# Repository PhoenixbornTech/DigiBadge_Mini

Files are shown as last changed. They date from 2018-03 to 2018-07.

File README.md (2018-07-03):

# DigiBadge_Mini
Upgraded and updated version of the [V2 DigiBadge](https://github.com/PhoenixbornTech/DigiBadgeV2). While keeping the same size profile, a few updates and changes have been made to the board and its software. But of course, you're wondering: What are the changes?

 - Added a small flash memory chip
 - Replaced the control "stick" with a set of three buttons
 - Broke out many pins: Analog 0-7 and Digital 2, 3, 4, 11, 12, and 13, along with VCC and GND. Buttons 0, 1, and 2 are assigned to D2, D3, and D4 respectively. I2C is available via A4 and A5, and SPI is available on D11, D12, and D13.
 - The FTDI connector is also broken out. If the FTDI chip isn't present, GND, VCC, RST, D0, and D1 can be accessed. 
 - No power switch! Instead, the device can be put into a super low power mode that effectively doesn't use any power, just like a TV remote.
 - The board has been redesigned so that these can be ordered and manufactured, instead of being entirely hand-assembled.
 - Other minor board tweaks have been made, including making the entire device not hard reset when an SD card is inserted.
 
## Plans for the FUTURE!
After selling these at BABSCon and getting some real-world usage out of them, there are a few things that need to be addressed, largely in the hardware. These fall under the category of [**Revision 2**](https://github.com/PhoenixbornTech/DigiBadge_Mini/milestone/3). Currently, those goals are:

 - Improving the buttons. The current ones are inexpensive, but not the easiest or most intuitive to use.
 - Labeling the FTDI orientation. The R1 board has no indication of pin direction, which can be annoying.
 - Add reverse voltage protection, to ensure nobody fries their board by accidentally putting the batteries in backwards.
 - Adding a voltage regulator. This will allow for consistent backlight brightness and utilizing more of the battery for a longer battery life. This will also allow for LiPo batteries to be used as well.
 
## How it works

With the latest releases, the DigiBadge operates using a Menu system that should be fairly straightforward.

From within a mode, pressing the left or right buttons will change which badge/flag/image is displayed, while pressing the center button will access the menu.

While in the Menu, pressing the left button (When looking at the screen) moves the cursor up, pressing the right button moves the cursor down, and the center button accesses the current selection. If the selection is a mode, the badge goes to that mode. If it is another menu, such as brightness, it goes into that menu.

Bear in mind that while the Slideshow Time menu will automatically return to the main menu on making a selection, **Brightness will not**. This is so you can select a brightness and see the difference. Exiting the menu locks the selection in.
 
The DigiBadge has four modes, in the order that they cycle through: **Color Communication Badge**, **Image Slideshow**, **Static Image**, and **Pride Flags**. Image Slideshow and Static Images are inaccessible (And greyed out) when there is no SD card detected.

The DigiBadge will *automatically* load the SD card when it is inserted. Thanks to moderately recent updates to the default Arduino library, this no longer requires edits to the SD library.
 
## Color Communication Badges
 
Color Communication Badges were *inspired* by BronyCon's use of them, but they were *originated* by the Autism Self-Advocacy Network. You can read what ASAN has to say on the Color Communication Badges on [their website](http://autisticadvocacy.org/2014/02/color-communication-badges/).
 
The badges on the DigiBadge are not identical to ASAN or BronyCon versions, as they have been adapted for viewing on a small screen. In the future, it would be great to allow for users to select a preference for style of these badges, but at the moment it is uncertain if that can be fit onto a device with the limited memory of an ATMega328p.

What you see on the DigiBadge is not an image file - It's programatically created each time it is displayed.
 
## Pride Flags
 
The DigiBadge also includes a variety of Pride Flags for users to display. Only a few flags were omitted, and those were ones that would be difficult to display programatically. As with the Color Communication Badges, these are created each time they are displayed.

There are currently *seven* Pride Flags built in to the DigiBadge Mini, in the order they appear: The **LGBT+ Flag**, the **Bisexual Flag**, the **Transexual Flag**, the **Pansexual Flag**, the **Asexual Flag**, the **Nonbinary Flag** and the **Agender Flag**.

## Image and Slideshow Modes

The Image and Slideshow modes are closely related. Both of them display 24-bit BMP images loaded from the SD card. Both of them will be skipped if no SD card is present. The difference is that the **Static Image** mode will display the image until told to change. The **Slideshow** mode will display a new semi-random image (It won't pick the current or previous image) every few seconds, and will display a "Play" icon in the corner.

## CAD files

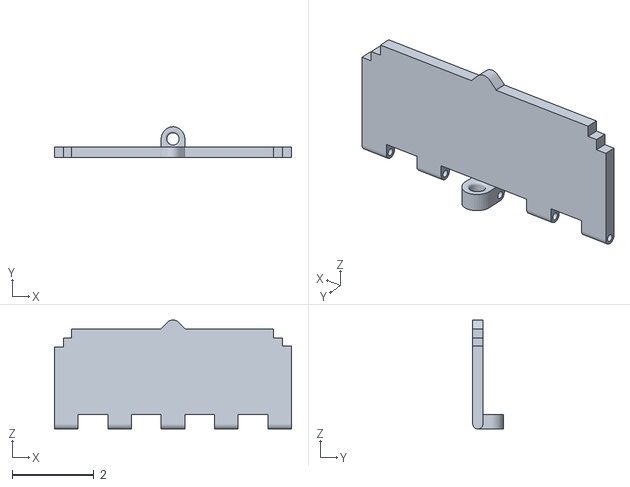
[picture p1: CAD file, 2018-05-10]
Case/DigiBadge V2 & Mini Lid.stl
5.80 x 0.75 x 2.67

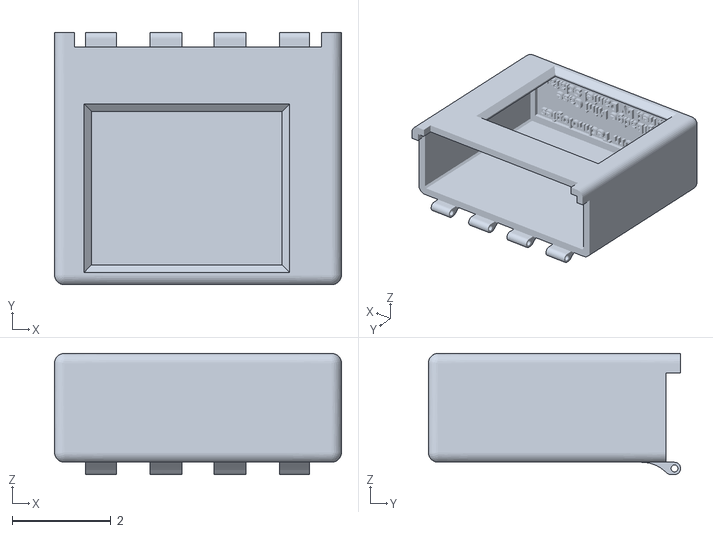
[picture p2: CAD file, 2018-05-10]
Case/DigiBadge Mini Case.stl
5.80 x 5.10 x 2.45

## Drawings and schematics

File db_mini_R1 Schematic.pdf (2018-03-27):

2 R1
10kΩ

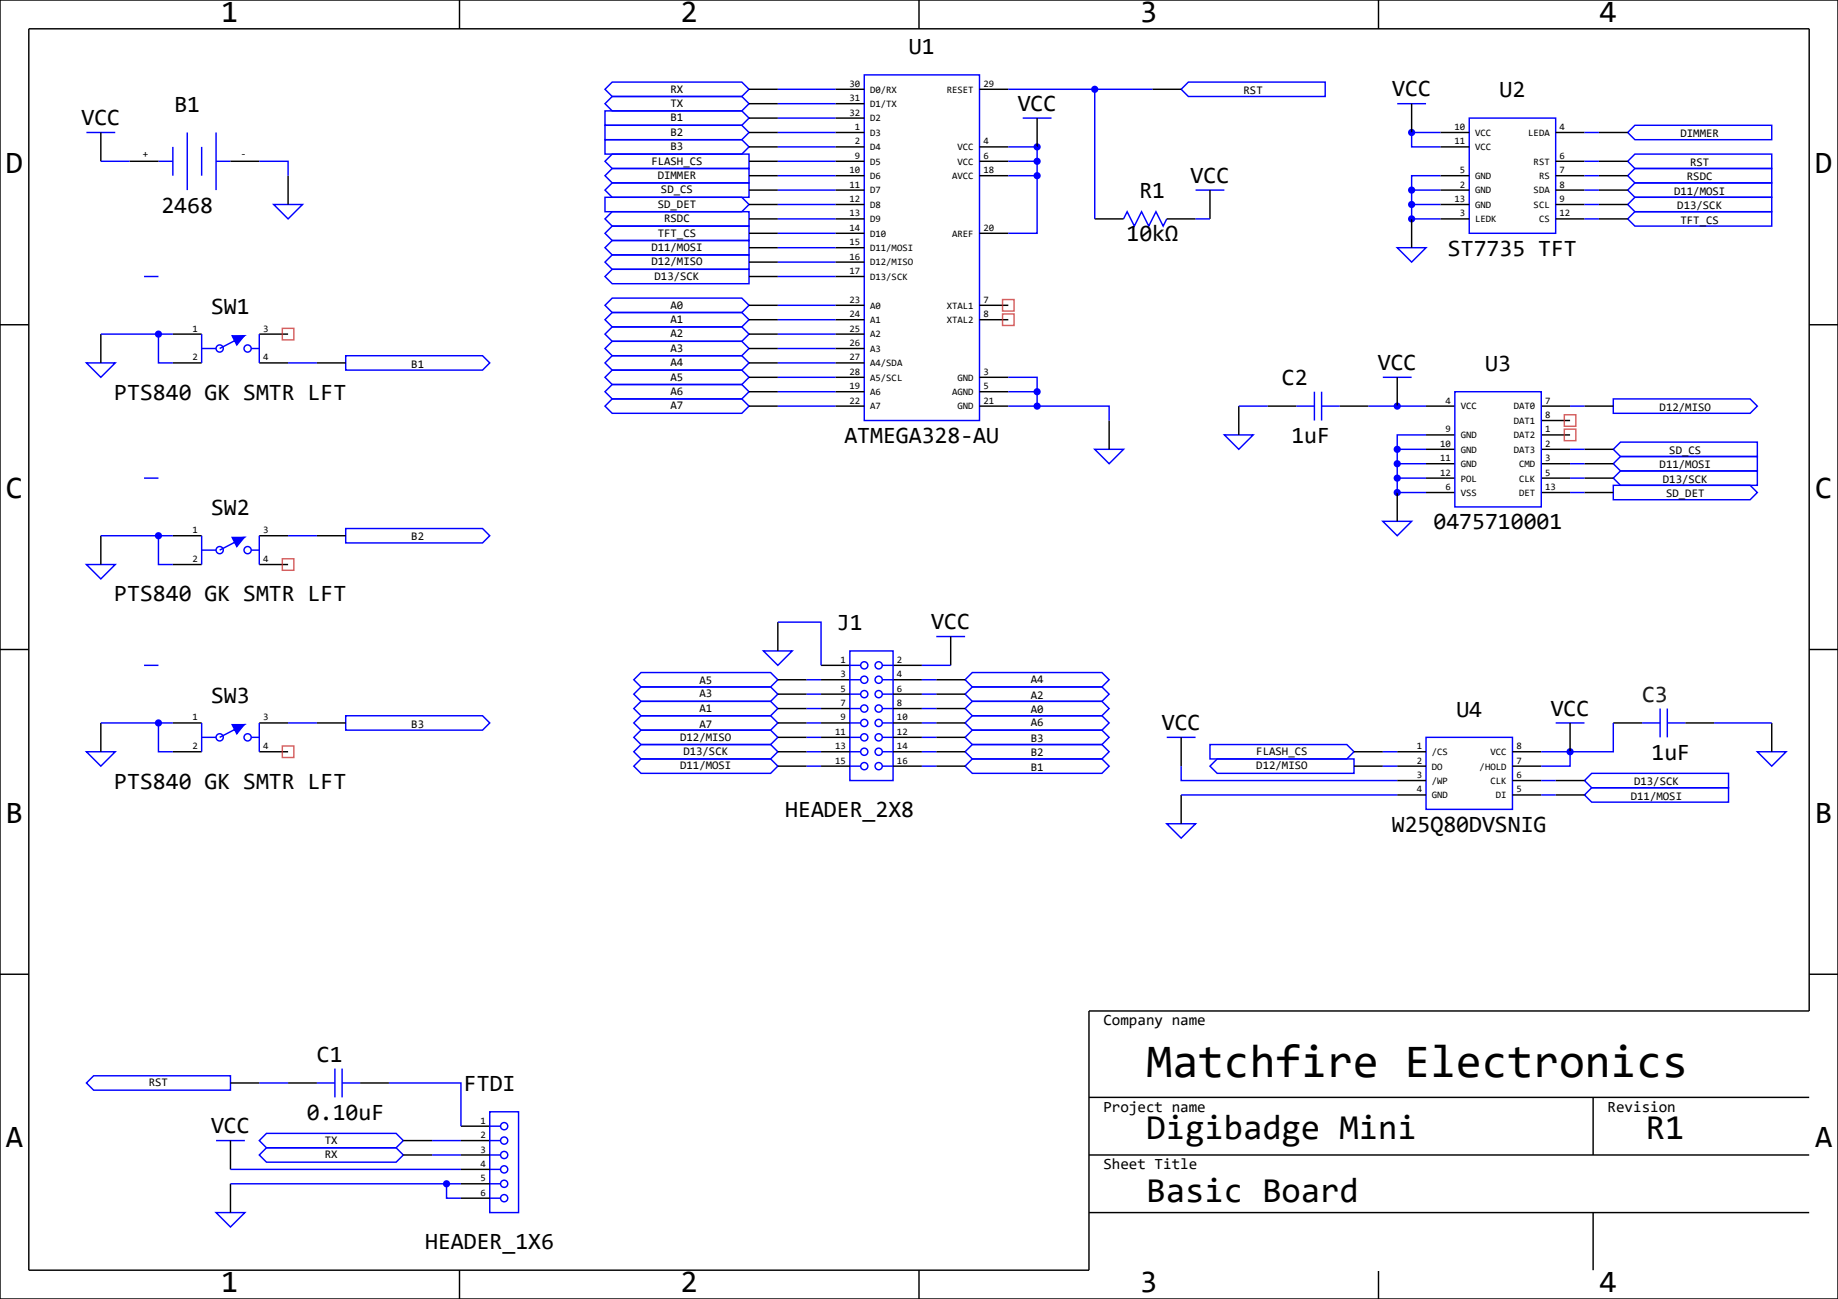
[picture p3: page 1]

Company name
Matchfire Electronics
Project name Digibadge Mini
Basic Board

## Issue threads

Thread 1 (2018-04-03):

Allow SD card to be loaded/re-loaded after startup

Andon-A, 2018-04-03:
Current implementation of the code does not allow for insertion of SD cards while the badge is running. The device needs to be manual hard reset.

Goals of this issue:

1. Enable the SD Card detection pin.
2. If a badge is running without a SD card and one is inserted, load it.
3. If a badge is running with an SD card and it is removed and re-inserted, reset the device. Without hacking the standard Arduino SD library, SD cards can't be reloaded.

Andon-A, 2018-05-06:
Commit [34ad042](https://github.com/PhoenixbornTech/DigiBadge_Mini/commit/121404a65850b7c9b673193664cdcd8491277d15) addresses this issue.

It functions *slightly* different than initial goals:

1. SD Card Detection is functioning, to enable the following:
2. If there is no SD card and one is inserted, the device will reset to load them (As the standard Arduino SD library doesn't allow reloading SD cards)
3. If there is an SD card and it is removed, the device adjusts the image count appropriately, and will then skip the image modes.

Closed 2018-05-06.

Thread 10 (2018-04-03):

Label FTDI Orientation

Andon-A, 2018-04-03:
Current FTDI orientation is unclear just by looking at the device. Improving the silkscreen to clearly mark the orientation would help immensely.

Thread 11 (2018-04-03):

Add Flash chip support

Andon-A, 2018-04-03:
Currently, the flash chip exists, but isn't used. That should be fixed.

Andon-A, 2018-05-07:
Commit [6288e9b](https://github.com/PhoenixbornTech/DigiBadge_Mini/commit/4f85b5977f58126d404e0ca74ab1a4cb20c3d47c) adds the SPIFlash library and utilizes it.

Closed 2018-05-07.

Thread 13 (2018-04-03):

Add .STL files for 3D Printed Case

Andon-A, 2018-04-03:
The goal is to have everything 100% open source, including the case files.

Andon-A, 2018-05-12:
These have been uploaded under the "Cases" folder.

Closed 2018-05-12.

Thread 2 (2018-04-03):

Software Reset

Andon-A, 2018-04-03:
A handful of things are easier if software reset is enabled. There are methodologies for an Arduino device to reset itself. One should be implemented.

Andon-A, 2018-04-03:
Code for the software reset will be used by #1 but allowing willing access/deliberate resets are further in the future.

Andon-A, 2018-05-12:
Not needed, and with the Menu System code taking up every last byte, it won't be implemented.

Closed 2018-05-12.

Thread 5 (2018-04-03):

Menu System

Andon-A, 2018-04-03:
Adding a menu system will allow more options, such as selecting modes without flipping through all of them, manually resetting the device, and the like. It will also allow the user to change options such as length between images in slideshow mode, or if the play button is shown in slideshow mode, or backlight brightness, and the like.

Andon-A, 2018-05-12:
Menu System has been completed and uploaded, with the pull request on my other monitor.

Closed 2018-05-12.

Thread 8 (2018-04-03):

Add Voltage Regulator

Andon-A, 2018-04-03:
A voltage regulator would allow for a significant increase in the utility of the device.

Things to keep in mind:

1. Boost regulating would allow for significant extension of battery life.
2. Adding a high/low regulator would allow for LiPo battery connection. If the appropriate regulator is selected, this could even apply to two LiPo AAA-sized cells.
3. Any regulator increases cost.
4. Physical space on the device is at a premium.

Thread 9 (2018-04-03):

Add Reverse Voltage Protection

Andon-A, 2018-04-03:
Ensuring that backwards batteries don't cause issues is always a good thing. It shouldn't be difficult to include the FTDI connector in the protection as well.

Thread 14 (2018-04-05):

Improve Buttons

Andon-A, 2018-04-05:
With the current button designs, people have a tendency to press perpendicular to the circuit board, instead of parallel from the top of the screen.

Sourcing buttons that are more visible and clearer as to their function would alleviate this issue.

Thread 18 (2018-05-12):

Update SD to use "SD Reset"

Andon-A, 2018-05-12:
Version 1.2.0 of the official Arduino SD library included [this fix](https://github.com/arduino-libraries/SD/pull/38), which allows for re-initialization of SD cards.

Rather than force-resetting the whole device, the SD card should be re-loaded when re-inserted.

This may make a software hard reset impossible, but it might not. Depends on how much space it needs. It may free up space.

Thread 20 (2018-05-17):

SPIMemory eats program space.

Andon-A, 2018-05-17:
SPIMemory (Formerly SPIFlash) eats twice as much program memory as the earlier version.

Something needs to be solved.

Current workaround: Use Verison 3.1.0 found [here](https://github.com/Marzogh/SPIMemory/releases/tag/v3.1.0)

Andon-A, 2018-05-17:
Additionally, SPIFlash.h, line 36 and line 64 need to be commented out on Version 3.1.0 - RUNDIAGNOSTIC and PRINTNAMECHANGEALERT, respectively.

Andon-A, 2018-05-22:
Looks like this should be addressed now: https://github.com/Marzogh/SPIMemory/issues/135

Marzogh reports that between fixes and a new memory-saving option, an additional 394 bytes are saved! That gives a lot of wiggle room for other things.

Andon-A, 2018-05-24:
Closing, as [This Commit](https://github.com/PhoenixbornTech/DigiBadge_Mini/commit/f57dc92b90c6c85ee3cc7d2d009534e7bb0dc764) fully integrates SPIMemory.

SPIMemory defaults to commenting out  `#define RUNDIAGNOSTIC` and `#define USES_SFDP`, so no modifications are needed to save space. Just install and go!

Closed 2018-05-24.

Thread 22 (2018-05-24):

Add Power LED

Andon-A, 2018-05-24:
Add an LED (Preferably to the front) that turns on when powered.

Potential issue: Having it on only when the device is on and not in sleep. Need to look into that.

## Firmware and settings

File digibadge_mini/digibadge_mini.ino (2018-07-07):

//DigiBadge Mini
//TODO list:
//-Backlight Control
//-TFT controls
//-Flash startup

//Libraries for TFT, SPI, SD, and flash.
#include <Adafruit_GFX.h>     // https://github.com/adafruit/Adafruit-GFX-Library
#include <Adafruit_ST7735.h>  // https://github.com/adafruit/Adafruit-ST7735-Library
#include <LowPower.h>         // https://github.com/rocketscream/Low-Power
#include <SPIMemory.h>         // https://github.com/Marzogh/SPIMemory
#include <SPI.h>
#include <SD.h>

//Defines.
//TFT CS is 10, DC is 9. TFT reset is tied to board reset.
#define BKLT 6 //Display backlight pin.
#define SDCS 7 //Chip Select for SD card
#define SDCD 8 //Card Detect line for SD card
#define FLCS 5 //Chip Select for Flash memory.
#define B0 2 //Button 0, or far left when viewing screen
#define B1 3 //Button 1, or center button
#define B2 4 //Button 2, or far right/next to SD card
#define BWK 0 //Wake on Interrupt 0/Button 0 press. Button 1 is also an option.
#define LowV 2800 //Low Voltage warning, in millivolts
#define CritV 2700 //Critical Voltage. Shut down below this.
#define LLEN 125 //Milliseconds the loop waits for.
#define VLEN 16 //Number of cycles before checking battery. 16 cycles at 125ms is about once every two seconds..

//Set up TFT and Flash
Adafruit_ST7735 tft = Adafruit_ST7735(10, 9, -1);
SPIFlash flash(FLCS);

//Code version.
//The byte or two extra in the code is used to allow slight variations in string size.
#define cver F("v1.2c")

//Variables.
byte x = 0;
byte scycles = 40; //Number of cycles it waits for slideshow.
byte bright = 10; //Brightness amount, in percent
byte md = 0; //Mode: 0 = Badge, 1 = Slideshow, 2 = Static Image, 3 = Flags
byte oldmd = 0; //Old mode. For when you enter the menu and just want to exit it.
byte badge = 0; //Current badge. 0 = Yellow, 1 = Red, 2 = Green
byte flag = 0; //Current flag. 0 = LGBT, 1 = Bi, 2 = Trans, 3 = Pan, 4 = Ace
byte menu = 0; //Current menu. 0 = main, 1 = slide speed, 2 = brightness, 3 = device info
byte select = 0; //Current menu selection. Line number. 0 = off.
byte oldselect = 0; //Old selection. For quickly re-displaying cursor.
byte bobs = 0; //Byte that stores bools as bits.
                //Bits 0, 1, and 2 are the respective Buttons.
                //Bit 3 is "SD Present" - For returning the status of the SD card detector.
                //Bit 4 is "Reset Timer" - Generally, when we manually change the image in a slideshow.
                //Bit 5 is "New Display" - Changing badge, changing image, etc
                //Bit 6 is "Low Battery"
                //Bit 7 is "Just Woke"
byte oldbobs = 0; //Storing previous buttons, to check against.
uint16_t imgnum = 0; //How many images we have.
uint16_t imgcur = 0; //Current image we are displaying.

void setup() {
  pinMode(B0, INPUT_PULLUP);
  pinMode(B1, INPUT_PULLUP);
  pinMode(B2, INPUT_PULLUP);
  pinMode(SDCD, INPUT_PULLUP);
  startSD();
  startFlash();
  startTFT();
  delay(2500); //Pause so we can actually SEE the screen.
  updateScreen();
}

void loop() {
  // put your main code here, to run repeatedly:
  x += 1;
  if (bitRead(bobs, 7)) {
    //We just woke up, so remove the interrupt and turn the screen back on.
    detachInterrupt(BWK); //Remove the interrupt.
    digitalWrite(6, HIGH);
    bitClear(bobs,7);
    x = 0; //Reset our counter.
    //GetBattery is deliberately placed after we turn back on.
    //This allows for the device to show something, although briefly.
    getBattery();
    delay(250); //Give us time to let go of buttons.
  }
  //Get our buttons. changed.
  getButtons();
  runButtons();
  //Next image in slideshow.
  if ((x % VLEN) == 0){
    //Check voltage.
    getBattery();
  }
  if (x > scycles){
    if (md == 1){
      //Change image if we're in slideshow mode.
      imgcur = randBMP();
      bitSet(bobs,5);
    }
    getBattery();
    x = 0;
  }
  //Update our screen if we have to.
  if (bitRead(bobs,5)){
    updateScreen();
    //Now that we've updated it, reset it.
    bitClear(bobs, 5);
  }
  if (bitRead(bobs, 4)){
    //We're resetting our timer.
    x = 0;
    bitClear(bobs, 4);
  }
  delay(LLEN);
}

void updateScreen(){
  if (md > 4){
    md = 0; //Just to be sure.
  }
  if (md == 0){
    //Badge Mode.
    drawBadge(badge);
  }
  else if ((md == 1) or (md == 2)){
    bmpDraw(grabBMP(imgcur),0,0);
  }
  else if (md == 3){
    drawFlag(flag);
  }
  else if (md == 4){
    drawMenu(menu, select);
  }
  if (md == 1){
    drawPlayIcon(146,2);
  }
}

void getButtons() {
  //Uses the first three bits of byte "bobs" as bools for buttons.
  oldbobs = bobs; //Store the previous iterations.  
  //Button 0. Left side facing screen.
  if (digitalRead(B0)){
    bitSet(bobs, 0);
  }
  else {
    bitClear(bobs, 0);
  }
  //Button 1. Center.
  if (digitalRead(B1)){
    bitSet(bobs, 1);
  }
  else {
    bitClear(bobs, 1);
  }
  //Button 2. Next to SD card.
  if (digitalRead(B2)){
    bitSet(bobs, 2);
  }
  else {
    bitClear(bobs, 2);
  }
  //SD Card Detect
  if (!digitalRead(SDCD)){
    //We have an SD card.
    bitSet(bobs, 3);
    if (bitRead(bobs, 3) and (!bitRead(oldbobs, 3))){
      //We now have an SD card, when we didn't before.
      //Attempt to re-start the SD card.
      startSD();
      bitSet(bobs, 5); //This makes it easy to notice things have loaded. Especially in a menu.
    }
  }
  else {
    bitClear(bobs, 3);
    if bitRead(oldbobs, 3) {
      //SD card removed while running.
      //We can't use images now.
      imgnum = 0;
      imgcur = 0;
      bitSet(bobs, 5); //As with above, makes it more noticeable that things have changed.
    }
  }
}

long getBattery(){
  //Retrieves the voltage of the batteries.
  //Using method prodivded at http://provideyourown.com/2012/secret-arduino-voltmeter-measure-battery-voltage/
  //Read the 1.1V internal reference against AVcc
  // Set the reference to VCC and measure the difference between the 1.1v and reference.
  ADMUX = _BV(REFS0) | _BV(MUX3) | _BV(MUX2) | _BV(MUX1);
  delay(2); //Allow Vref to settle.
  ADCSRA |= _BV(ADSC); // Start conversion
  while (bit_is_set(ADCSRA, ADSC)); // measuring
  uint8_t low  = ADCL; // must read ADCL first - it then locks ADCH
  uint8_t high = ADCH; // unlocks both
  long mV = (high << 8) | low;
  mV = 1125300L / mV; // Calculate Vcc (in mV); 1125300 = 1.1*1023*1000
  if (mV <= LowV){
    //We have low voltage.
    //Batteries are still fairly good, but backlight power starts waning quite fast.
    bitSet(bobs, 6);
  }
  else if ((mV > (LowV + 250)) and bitRead(bobs, 6)){
    //If "Low Battery" bit is set, and we are now higher than the Low Voltage, clear the low battery alert.
    //A small cushion is added to ensure we don't get a set/unset with voltage fluctuations.
    //Realistically speaking, we won't need this, but there's a chance we'll go to, say, external power.
    bitClear(bobs, 6);
  }
  if (mV <= CritV){
    //We turn off at this point.
    //As we check the battery voltage fairly often, we can just shut off.
    digitalWrite(6, LOW);
    attachInterrupt(BWK, wakeUp, LOW);
    delay(300);
    LowPower.powerDown(SLEEP_FOREVER, ADC_OFF, BOD_OFF); 
  }
  return mV;
}

void runButtons(){
  //New, for Menus!
  //Improvements: "else if" instead of "if"
  //Ensures proper button priority.
  //bitSet(bobs, 5); //Menus won't require full screen reset.
  if (!bitRead(bobs, 1)){
    //Button 1 (Center)
    //Most important button!
    bitSet(bobs, 5); //We're changing menus, or modes.
    //If we're in a non-Menu mode, bring us to Menu mode.
    if(md != 4){
      oldmd = md;
      md = 4;
      menu = 0;
      select = 1;
    }
    else if(md == 4){
      //Do the thing. For the menu.
      if (menu == 0){
        if(select == 1){
          md = 0; //Enter Badge Mode.
        }
        else if (select == 2){
          md = 3; //Enter Flag Mode.
        }
        else if ((select == 3) and (imgnum > 0)){
          md = 2; //Enter Image mode, but only if we have images.
        }
        else if ((select == 4) and (imgnum > 1)){
          md = 1; //Enter Slideshow mode, but only if we have images.
          x = 0; //Reset our timer, just in case.
        }
        else if ((select == 4) and (imgnum == 1)){
          md = 2; //Enter image mode for one image.
        }
        else if (select == 5){
          menu = 3; //Device Info
          select = 0;
        }
        else if (select == 6){
          menu = 1; //Slideshow speed
          select = 1;
        }
        else if (select == 7){
          menu = 2; //Brightness.
          select = 1;
        }
        else if (select == 8){
          md = oldmd; //Make sure we wake up in our old mode.
          //saveSettings(); //Save settings. Shouldn't be needed, but we ARE turning off, so...
          napTime();
        }
        if(((select >=1) and (select <= 4)) or (select == 8)){
          //We're selecting a mode, OR shutting down.
          saveSettings();
        }
      }
      else if (menu == 1){
        //Slideshow speed!
        if((select > 0) and (select < 13)){
          //We're selecting a delay.
          scycles = 8 * select; //Yay simple!
          x = 0; //Reset to 0 for slideshow shenanigans.
          select = 1;
          menu = 0;
        }
        else {
          //Exiting this menu.
          select = 1;
          menu = 0;
        }
      }
      else if (menu == 2){
        //Brightness
        if((select > 0) and (select < 11)){
          //We're selecting a brightness.
          bright = 10 * select;
          setLight(bright);
          //So, to easily see results and change them
          //DON'T exit tue current menu.
          //Also don't redraw it.
          bitClear(bobs, 5);
        }
        else {
          //Exit this menu. Save settings.
          select = 1;
          menu = 0;
        }
      }
      else if (menu == 3){
        //Device Info!
        //Simply return to main menu.
        select = 1;
        menu = 0;
      }
    }
  }
  else if (!bitRead(bobs, 0)){
    //Button 0 (Far left when looking at screen)
    if (md == 0){
      //Badge mode. Decrese badge by one.
      badge -= 1;
      if (badge > 2){
        //Only three badges.
        badge = 2; //We're decreasing, so go to the highest.
      }
    }
    else if (md == 1){
      //Slideshow!
      //New random image.
      imgcur = randBMP();
    }
    else if (md == 2){
      //Still image.
      imgcur -= 1; //Reduce by one!
      if (imgcur > imgnum){
        //We've wrapped around.
        imgcur = imgnum;
      }
    }
    else if (md == 3){
      //Flags!
      flag -= 1;
      if (flag > 6){
        //Wrap around
        flag = 6;
      }
    }
    else if (md == 4){
      //Go "Down" in the menu selection.
      oldselect = select;
      if (menu == 0){
        //Main menu. 8 max.
        select -= 1;
        if (select == 0){
          select = 8;
        }
      }
      else if (menu == 1){
        //Slideshow Time Menu. 13 max.
        select -= 1;
        if (select == 0){
          select = 13;
        }
      }
      else if (menu == 2){
        //Brightness. 11 Max.
        select -= 1;
        if (select == 0){
          select = 11;
        }
      }
      drawCursor(select, oldselect);
    }
  }
  else if (!bitRead(bobs, 2)){
    //Button 2 (Far right, next to SD card)
    if (md == 0){
      //Badge mode. Increase badge by one.
      badge += 1;
      if (badge > 2){
        //Only three badges.
        badge = 0; //Increasing, so wrap around.
      }
    }
    else if (md == 1){
      //Slideshow!
      //New random image.
      imgcur = randBMP();
    }
    else if (md == 2){
      //Still image.
      imgcur += 1; //Increase by one!
      if (imgcur > imgnum){
        //We've wrapped around.
        imgcur = 1;
      }
    }
    else if (md == 3){
      //Flags!
      flag += 1;
      if (flag > 6){
        //Wrap around
        flag = 0;
      }
    }
    else if (md == 4){
      //Go "Up" in the menu selection.
      oldselect = select;
      if (menu == 0){
        //Main menu. 8 max.
        select += 1;
        if (select > 8){
          select = 1;
        }
      }
      else if (menu == 1){
        //Slideshow menu. 13 max.
        select += 1;
        if (select > 13){
          select = 1;
        }
      }
      else if (menu == 2){
        //Brightness menu. 11 max.
        select += 1;
        if (select > 11){
          select = 1;
        }
      }
      drawCursor(select, oldselect);
    }
  }
  if ((!bitRead(bobs, 0) or !bitRead(bobs,2)) and (md != 4)){
    //All non-Menu changes require screen update and settings save.
    bitSet(bobs, 5);
    saveSettings();
  }
}

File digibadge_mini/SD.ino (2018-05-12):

void startSD(){
  //We haven't checked any buttons yet, so do it manually.
  if (!digitalRead(SDCD)) {
    //We have an SD card physically present. Attempt to start it.
    bitSet(bobs, 3); //To prevent from immediately resetting.
    if (SD.begin(SDCS)) {
      imgnum = countBMP();
      if (imgnum > 0) {
        //"Current Image" starts at 1. Adjust accordingly.
        imgcur = 1;
      }
    }
  }
}

uint16_t countBMP(){
  uint16_t bmpcount = 0;
  //Open directory, then rewind it. Just in case someone hasn't been kind.
  File dir = SD.open("/");
  dir.rewindDirectory();
  //Start checking files.
  File fi = dir.openNextFile();
  while (fi) {
    //Check it.
    if (bmpCheck(fi)){
      //We have a valid, 24-bit BMP file.
      bmpcount += 1;
    }
    //We're done here.
    fi.close();
    delay(5); //Don't go too fast.
    fi = dir.openNextFile();
  }
  dir.rewindDirectory();
  dir.close();
  return bmpcount;
}


bool bmpCheck(File bmpFile) {
   //Check a File to see if it's an appropriate BMP file.
   //Silently fail directories.
   //if (bmpFile.isDirectory()){
   // return false; 
   //}
   if (read16(bmpFile) == 0x4D42) { // BMP signature
    (void)read32(bmpFile); //Read, but ignore, file size.
    (void)read32(bmpFile); //Same with creator bytes
    (void)read32(bmpFile); //Same with start of image data.
    (void)read32(bmpFile); //Header size.
    (void)read32(bmpFile); //Width.
    (void)read32(bmpFile); //Height.
    (void)read16(bmpFile); //Planes.
    //Now the important stuff!
    //First is Bit Depth and second is Compression.
    if((read16(bmpFile) == 24) && (read32(bmpFile) == 0)){
      return true;
    }
    //else {
      //Not a 24-bit BMP file.
    //  return false;
    //}
  }
  else {
    //File is not a BMP
    return false;
  }
}

uint16_t randBMP(){
  //Returns a random image number.
  //Makes sure we don't pull the current or previous image, unless there are only two images.
  if (imgnum == 1){
    //Only one image.
    return 1;
  }
  else if (imgnum == 2){
    //Two images. Return the previous image.
    if (imgcur == 1){
      return 2;
    }
    else {
      return 1;
    }
  }
  else {
    uint16_t res = random(1,imgnum+1);
    while (res == imgcur){
      res = random(1,imgnum+1);
    }
    return res;
  }
}

uint16_t numBMP(char* filename){
  uint16_t count = 0;
  File dir = SD.open("/");
  dir.rewindDirectory();
  File fi = dir.openNextFile();
  while(fi){
    if (bmpCheck(fi)){
      //A valid BMP.
      count += 1; 
    }
    if (fi.name() == filename){
      fi.close();
      dir.rewindDirectory();
      dir.close();
      return count;
    }
    fi.close();
    delay(5);
    fi = dir.openNextFile();
  }
  dir.rewindDirectory();
  dir.close();
  return 0;
}

char* grabBMP(uint16_t bmpnum){
  if (bmpnum > imgnum) {
    //We don't have that many images.
    //Retrieve the last one.
    bmpnum = imgnum;
  }
  uint16_t count = 0;
  File dir = SD.open("/");
  dir.rewindDirectory();
  char* bmpName;
  File fi = dir.openNextFile();
  while(fi) {
    if (bmpCheck(fi)){
      //A valid file.
      count += 1; //Increment the count.
      if (count == bmpnum){
        //The file we want
        bmpName = fi.name();
        fi.close();
        dir.rewindDirectory();
        dir.close();
        return bmpName;
      }
    }
    //Close the file, move to next one.
    fi.close();
    delay(5);
    fi = dir.openNextFile();
  }
  //Give us the name.
  dir.rewindDirectory();
  dir.close();
  return bmpName;
}

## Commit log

2018-05-06 Fixes border issues on LGBT Flag
    Fixes border issues on LGBT flag.
    [flags.ino]
2018-05-06 Allow hot-swapping of SD cards
    Addresses issue #1 Utilizes a device reset when a card is inserted.
    Updates images when card is removed.
    [SD.ino, sleeproutines.ino]
2018-05-06 Updated README
    Added descriptions of what everything does, and what buttons do what,
    etc.
2018-05-10 Added case .STL files
    Uploaded the STL files for the DigiBadge Mini case.
    [DigiBadge Mini Case.stl, DigiBadge V2 & Mini Lid.stl]
2018-05-10 Organization
    Moved case files to their own folder. Should have done that to begin
    with.
    [DigiBadge Mini Case.stl, DigiBadge V2 & Mini Lid.stl]
2018-05-11 Remove "proto" from code name
    Not a prototype anymore.
2018-05-12 Updates with links to libraries
    Updates digibadge_mini.ino with links to the Arduino libraries used.
    Also worth noting that after I updated my versions of these libraries,
    there are now 34 bytes available.
2018-05-12 SD Reloading
    Addresses #18 to allow a smoother loading of SD card.
    Also addresses minor bug with Flags - If the number was out of range,
    they'd fail to load entirely.
    More code cleanup is included as well.
    [SD.ino, TFT.ino, digibadge_mini.ino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]
2018-05-15 Fixes defaulting to badge mode bug
    Fix for #19 and clarification of code version comment.
    [digibadge_mini.ino]
2018-05-24 SPIMemory, Bugfixes, and Flash Error Checking
    Updates to SPIMemory flash library, which saves some space.
    Fixes the badge not remembering Slideshow/Still Image mode on full
    reboot
    Adds error checking to ALL settings when loading from flash memory, and
    updates a few other checks to be more thorough.
    [badges.ino, digibadge_mini.ino, flags.ino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]
2018-06-02 Fixes issues, adds more flags
    Actually fixes a few things that should have made it into 1.2a but
    didn't, and also adds Agender and Nonbinary Pride Flags.
    [digibadge_mini.ino, flags.ino, flash_storage.ino]
2018-07-07 Minor update: Settings validation, add default values check.
    Ensures that loading erroneous numbers for badges, flags, and brightness
    will automatically fix itself.
    Adjust minimum cycle time.
    Add a "Save Default" function that will save some default settings to
    badges that haven't had this.
    At time of commit, compiles with 30700 out of 30720 bytes used.
    [TFT.ino, badges.ino, digibadge_mini.ino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]
